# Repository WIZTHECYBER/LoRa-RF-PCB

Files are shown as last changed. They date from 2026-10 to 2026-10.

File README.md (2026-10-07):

# LoRa-RF-PCB







A custom PCB for long range radio frequency (LoRa) communication, built around an RP2040 and a Semtech SX1262 radio.


## Overview

I saw a guideline for a LoRa RF devboard in Forge Blueprint and decided to make my own. I did made schematics with help of AI and then designed and routed the PCB myself!!

###This PCB contains following components###
|MCU, radio, and flash all on one PCB, powered and programmed over USB-C.|

## Schematics Components 

| Part | Role |
|---|---|
| RP2040 | Microcontroller — runs everything |
| SX1262 | LoRa radio chip — handles the actual RF signal |
| 16MB flash | Stores the firmware |
| USB-C | Power and programming |
| RF switch + filter + antenna | Gets the signal in and out cleanly |
| Crystal oscillators | Reference clocks for the MCU and radio |
| LDO regulator | Power supply |
| Boot / Reset buttons | Standard flashing controls |

586520549-c6413717-07d1-4046-96aa-68a0806cc8d6

## Build Journey

This was my first time working with a 4-layer PCB, and it showed me why layer count matters — figuring it out took a while, but I learned a lot along the way. I used **Gemini** for help with the schematics.

From there, I moved on to placing components and routing the PCB myself. 


RF signal paths need to be straight and length-matched, which made that part of the routing genuinely tricky — it took about 2 days to fully route the board. Once the hardware was done, I wrote the firmware to bring it to life.


## Bill of Materials (BOM)

| Designator(s) | Part | Value / Footprint | Qty |
|---|---|---|---|
| U1 | RP2040 | Microcontroller, QFN-56 | 1 |
| U2 | SX1262IMLTRT | LoRa/FSK Transceiver, QFN-24 | 1 |
| U3 | W25Q128JVS | 16MB SPI Flash, SOIC-8 | 1 |
| U4 | PE4259 | RF Switch, SOT-363 | 1 |
| U5 | AP2112K-3.3 | 3.3V LDO Regulator, SOT-23-5 | 1 |
| USB_C | USB-C Receptacle | USB 2.0, 16-pin | 1 |
| J3 | Pin Socket, 1x04 | For a 0.96" OLED display | 1 |
| AE111 | U.FL Connector | For an external antenna | 1 |
| FL1 | Balun/Filter | Johanson 0900FM15K0039 | 1 |
| Y1 | Crystal | 32MHz (radio ref clock) | 1 |
| Y2 | Crystal | 12MHz (MCU ref clock) | 1 |
| BOOT | Tactile Switch | B3U-1000P | 1 |
| RESET | Tactile Switch | B3U-1000P | 1 |
| LED1 | LED | Blue | 1 |
| L1 | Inductor | 47nH | 1 |
| L2 | Inductor | 9.1nH | 1 |
| L3 | Inductor | 15µH (PA regulator) | 1 |
| R1 | Resistor | 100Ω | 1 |
| R2, R3, R7* | Resistor | 1kΩ | 3 |
| R4, R10 | Resistor | 10kΩ | 2 |
| R5, R6 | Resistor | 5.1kΩ (USB CC) | 2 |
| R8, R9 | Resistor | 27Ω (USB D+/D−) | 2 |
| R11, R12 | Resistor | 4.7kΩ | 2 |
| C1, C8, C9, C13, C14, C17–C23 | Capacitor | 100nF | 12 |
| C11, C12 | Capacitor | 27pF (crystal load) | 2 |
| C15, C16 | Capacitor | 1µF | 2 |
| C24, C25 | Capacitor | 10µF | 2 |
| C2 | Capacitor | 1nF | 1 |
| C3 | Capacitor | 39pF | 1 |
| C4, C5 | Capacitor | 3.3pF (RF matching) | 2 |
| C6 | Capacitor | 47pF | 1 |
| C7 | Capacitor | 47nF | 1 |
| C10 | Capacitor | 470nF (PA regulator) | 1 |

## Getting It Built

The RP2040, SX1262, and flash chip are all fine-pitch QFN parts, so this isn't a hand-soldering job — it needs PCBA (assembled by the fab) rather than a bare PCB.

## AI Use

Being upfront about it: I used Gemini for help with component selection and schematic routing, did the PCB design and routing myself!!.

## License

Released under [CERN-OHL-S](https://ohwr.org/cern_ohl_s_v2.txt) — feel free to fork it, fab it, and build on it.

Thanks for taking the time to look through this one — it was one of the more challenging boards I've built so far, and I learned a ton doing it. If you spot something worth improving, or you end up building one yourself, I'd genuinely love to hear about it. Feel free to open an issue or reach out.📡

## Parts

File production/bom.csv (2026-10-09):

Designator | Footprint | Quantity | Value | LCSC Part #
AE111 | U.FL_Hirose_U.FL-R-SMT-1_Vertical | 1 | Antenna | C88374
C1, C13, C14, C17, C18, C19, C20, C21, C22, C23, C8, C9 | 0603 | 12 | 100nF | C14663
C10 | 0603 | 1 | 470nF | C1623
C11, C12 | 0603 | 2 | 27pF | C1656
C15, C16 | 0603 | 2 | 1uF | C15849
C2 | 0603 | 1 | 1nF | C1588
C24, C25 | 0805 | 2 | 10uF | C15850
C3 | 0603 | 1 | 39pF | C302067
C4, C5 | 0603 | 2 | 3.3pF | C1660
C6 | 0603 | 1 | 47pF | C1671
C7 | 0603 | 1 | 47nF | C1622
FL1 | Balun_Johanson_0900FM15K0039 | 1 | 0900FM15K0039 | C5224443
J3 | PinSocket_1x04_P2.54mm_Vertical | 1 | Conn_01x04_Socket | C2897367
L1 | 0603 | 1 | 47nH | C98076
L2 | 0603 | 1 | 9.1nH | C251803
L3 | 0805 | 1 | 15uH | C383402
LED1 | 0603 | 1 | BLUE | C2288
R1 | 0603 | 1 | 100 | C22775
R10, R4 | 0603 | 2 | 10K | C25804
R11, R12 | 0603 | 2 | 4.7K | C23162
R2, R3, R7 | 0603 | 3 | 1K | C21190
R5, R6 | 0603 | 2 | 5.1K | C23186
R8, R9 | 0603 | 2 | 27 ohm | C25190
SW1 | SW_SPST_B3U-1000P | 1 | BOOT | C231329
SW2 | SW_SPST_B3U-1000P | 1 | RESET | C231329
U1 | QFN-56-1EP_7x7mm_P0.4mm_EP3.2x3.2mm | 1 | RP2040 | C2040
U2 | QFN-24-1EP_4x4mm_P0.5mm_EP2.6x2.6mm | 1 | SX1262IMLTRT | C191341
U3 | SOIC-8_5.3x5.3mm_P1.27mm | 1 | W25Q128JVS | C97521
U4 | SOT-363_SC-70-6 | 1 | PE4259 | C470892
U5 | SOT-23-5 | 1 | AP2112K-3.3 | C51118
USB-C | USB_C_Receptacle_HRO_TYPE-C-31-M-12 | 1 | USB_C_Receptacle_USB2.0_16P | C165948
Y1 | Crystal_SMD_3225-4Pin_3.2x2.5mm_HandSoldering | 1 | 32MHz | C9009
Y2 | Crystal_SMD_3225-4Pin_3.2x2.5mm_HandSoldering | 1 | 12MHz | C9002

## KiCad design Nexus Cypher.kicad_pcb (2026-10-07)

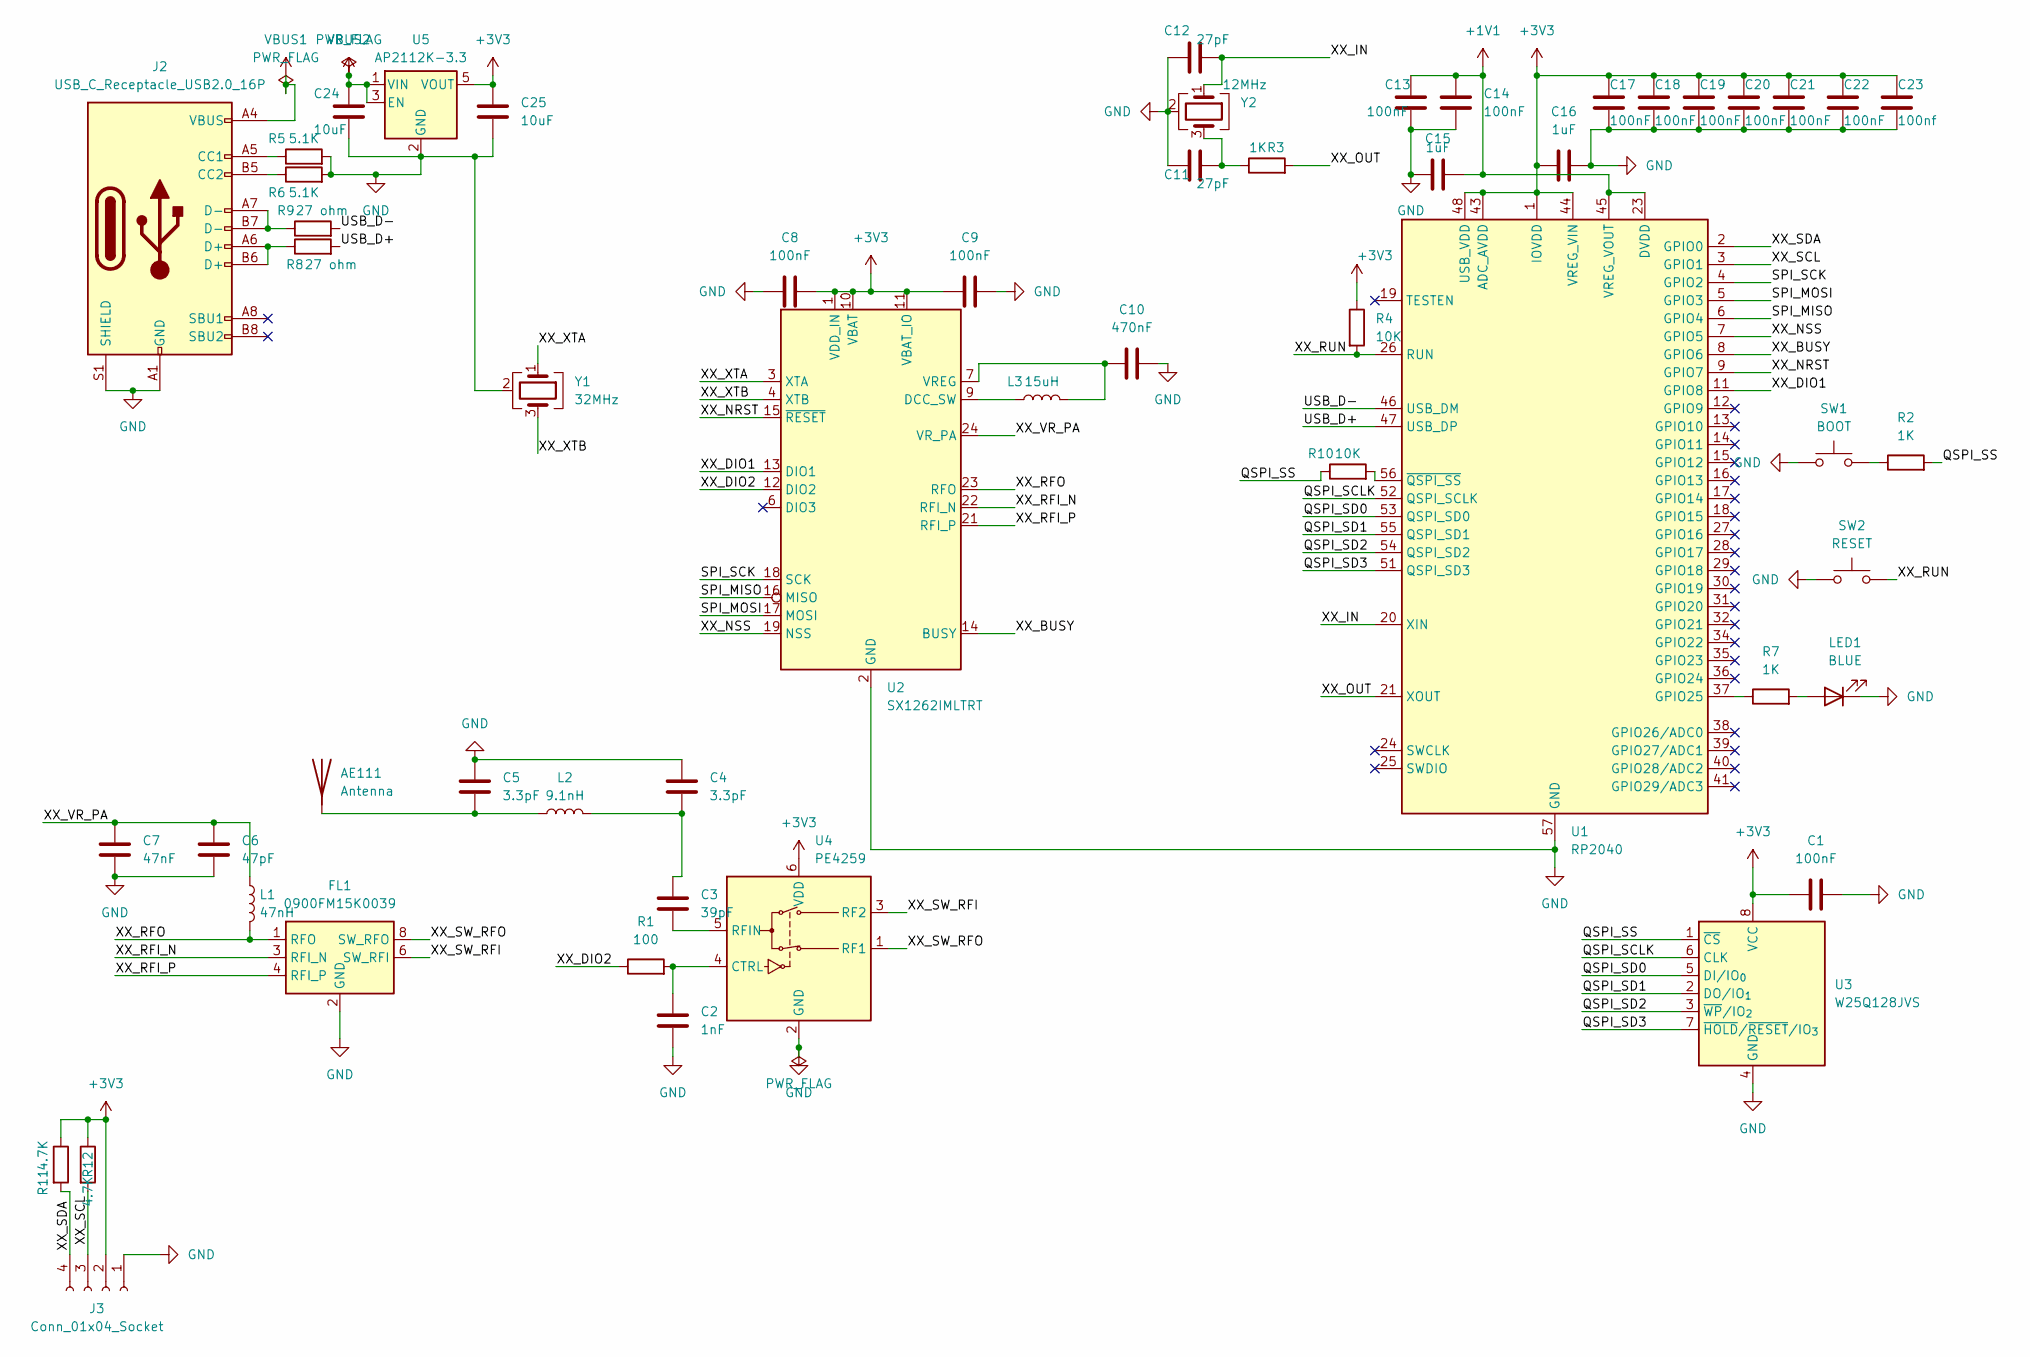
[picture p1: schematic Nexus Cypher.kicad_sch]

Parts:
AE111: Antenna; U.FL_Hirose_U.FL-R-SMT-1_Vertical
C1, C8, C9, C13, C14, C17, C18, C19, C20, C21, C22: 100nF; C_0603_1608Metric
C2: 1nF; C_0603_1608Metric
C3: 39pF; C_0603_1608Metric
C4, C5: 3.3pF; C_0603_1608Metric
C6: 47pF; C_0603_1608Metric
C7: 47nF; C_0603_1608Metric
C10: 470nF; C_0603_1608Metric
C11, C12: 27pF; C_0603_1608Metric
C15, C16: 1uF; C_0603_1608Metric
C23: 100nf; C_0603_1608Metric
C24, C25: 10uF; C_0805_2012Metric
FL1: 0900FM15K0039; Balun_Johanson_0900FM15K0039
J2: USB_C_Receptacle_USB2.0_16P; USB_C_Receptacle_HRO_TYPE-C-31-M-12
J3: Conn_01x04_Socket; PinSocket_1x04_P2.54mm_Vertical
L1: 47nH; L_0603_1608Metric
L2: 9.1nH; L_0603_1608Metric
L3: 15uH; L_0805_2012Metric
LED1: BLUE; LED_0603_1608Metric
R1: 100; R_0603_1608Metric
R2, R3, R7: 1K; R_0603_1608Metric
R4, R10: 10K; R_0603_1608Metric
R5, R6: 5.1K; R_0603_1608Metric
R8, R9: 27 ohm; R_0603_1608Metric
R11, R12: 4.7K; R_0603_1608Metric
SW1: BOOT; SW_SPST_B3U-1000P
SW2: RESET; SW_SPST_B3U-1000P
U1: RP2040; QFN-56-1EP_7x7mm_P0.4mm_EP3.2x3.2mm
U2: SX1262IMLTRT; QFN-24-1EP_4x4mm_P0.5mm_EP2.6x2.6mm
U3: W25Q128JVS; SOIC-8_5.3x5.3mm_P1.27mm
U4: PE4259; SOT-363_SC-70-6
U5: AP2112K-3.3; SOT-23-5
Y1: 32MHz; Crystal_SMD_3225-4Pin_3.2x2.5mm_HandSoldering
Y2: 12MHz; Crystal_SMD_3225-4Pin_3.2x2.5mm_HandSoldering

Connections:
+1V1: C13.1, C14.1, C15.2, U1.23 (DVDD), U1.45 (VREG_VOUT), U1.50 (DVDD)
+3V3: C1.1, C8.2, C9.1, C16.1, C17.1, C18.1, C19.1, C20.1, C21.1, C22.1, C23.1, C25.1, J3.2, R4.1, R11.1, R12.1, U1.1 (IOVDD), U1.10 (IOVDD), U1.22 (IOVDD), U1.33 (IOVDD), U1.42 (IOVDD), U1.43 (ADC_AVDD), U1.44 (VREG_VIN), U1.48 (USB_VDD), U1.49 (IOVDD), U2.1 (VDD_IN), U2.10 (VBAT), U2.11 (VBAT_IO), U3.8 (VCC), U4.6 (VDD), U5.5 (VOUT)
/QSPI_SCLK: U1.52 (QSPI_SCLK), U3.6 (CLK)
/QSPI_SD0: U1.53 (QSPI_SD0), U3.5 (DI/IO_{0})
/QSPI_SD1: U1.55 (QSPI_SD1), U3.2 (DO/IO_{1})
/QSPI_SD2: U1.54 (QSPI_SD2), U3.3 (~WP/IO_{2})
/QSPI_SD3: U1.51 (QSPI_SD3), U3.7 (~HOLD/~RESET/IO_{3})
/QSPI_SS: R2.2, R10.1, U3.1 (~CS)
/SPI_MISO: U1.6 (GPIO4), U2.16 (MISO)
/SPI_MOSI: U1.5 (GPIO3), U2.17 (MOSI)
/SPI_SCK: U1.4 (GPIO2), U2.18 (SCK)
/USB_D+: R8.2, U1.47 (USB_DP)
/USB_D-: R9.2, U1.46 (USB_DM)
/XX_BUSY: U1.8 (GPIO6), U2.14 (BUSY)
/XX_DIO1: U1.11 (GPIO8), U2.13 (DIO1)
/XX_DIO2: R1.1, U2.12 (DIO2)
/XX_IN: C12.2, U1.20 (XIN), Y2.1
/XX_NRST: U1.9 (GPIO7), U2.15 (~RESET)
/XX_NSS: U1.7 (GPIO5), U2.19 (NSS)
/XX_OUT: R3.2, U1.21 (XOUT)
/XX_RFI_N: FL1.3 (RFI_N), U2.22 (RFI_N)
/XX_RFI_P: FL1.4 (RFI_P), U2.21 (RFI_P)
/XX_RFO: FL1.1 (RFO), L1.2, U2.23 (RFO)
/XX_RUN: R4.2, SW2.2, U1.26 (RUN)
/XX_SCL: J3.3, R12.2, U1.3 (GPIO1)
/XX_SDA: J3.4, R11.2, U1.2 (GPIO0)
/XX_SW_RFI: FL1.6 (SW_RFI), U4.3 (RF2)
/XX_SW_RFO: FL1.8 (SW_RFO), U4.1 (RF1)
/XX_VR_PA: C6.1, C7.1, L1.1, U2.24 (VR_PA)
/XX_XTA: U2.3 (XTA), Y1.1
/XX_XTB: U2.4 (XTB), Y1.3
GND: C1.2, C2.2, C4.2, C5.2, C6.2, C7.2, C8.1, C9.2, C10.2, C11.2, C12.1, C13.2, C14.2, C15.1, C16.2, C17.2, C18.2, C19.2, C20.2, C21.2, C22.2, C23.2, C24.2, C25.2, FL1.2 (GND), FL1.5 (GND), FL1.7 (GND), FL1.9 (GND), FL1.10 (GND), J2.A1 (GND), J2.A12 (GND), J2.B1 (GND), J2.B12 (GND), J2.S1 (SHIELD), J3.1, LED1.1 (K), R5.2, R6.2, SW1.1, SW2.1, U1.57 (GND), U2.2 (GND), U2.5 (GND), U2.8 (GND), U2.20 (GND), U2.25 (GND), U3.4 (GND), U4.2 (GND), U5.2 (GND), Y1.2 (G), Y1.4 (G), Y2.2 (G), Y2.4 (G); also elsewhere on the board
unnamed: AE111.1 (A_1), C5.1, L2.1
unnamed: C3.1, C4.1, L2.2
unnamed: C11.1, R3.1, Y2.3
unnamed 35: J2.A5 (CC1), R5.1; also elsewhere on the board
unnamed 36: J2.B5 (CC2), R6.1; also elsewhere on the board
unnamed 37: J2.A6 (D+), J2.B6 (D+), R8.1; also elsewhere on the board
unnamed 38: J2.A7 (D-), J2.B7 (D-), R9.1; also elsewhere on the board
unnamed: J2.A4 (VBUS), J2.A9 (VBUS), J2.B4 (VBUS), J2.B9 (VBUS)
unnamed: LED1.2 (A), R7.2
unnamed: R2.1, SW1.2
unnamed: R7.1, U1.37 (GPIO25)
unnamed: R10.2, U1.56 (~QSPI_SS)
unnamed: L3.1, U2.9 (DCC_SW)
unnamed: C10.1, L3.2, U2.7 (VREG)
unnamed: C2.1, R1.2, U4.4 (CTRL)
unnamed: C3.2, U4.5 (RFIN)
VBUS2: C24.1, U5.1 (VIN), U5.3 (EN)

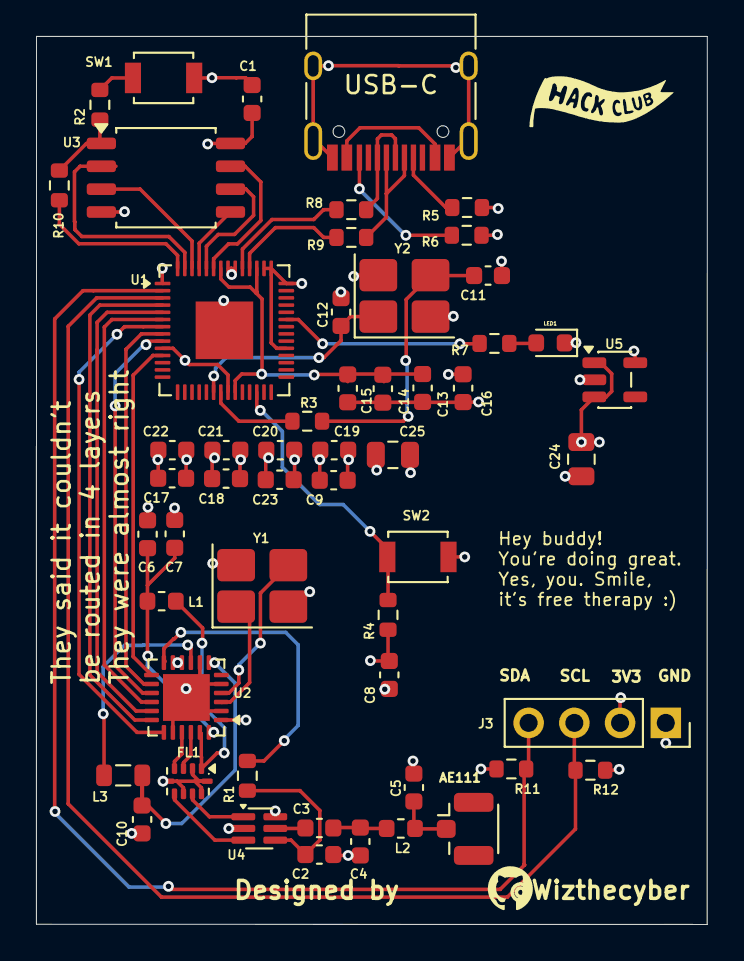
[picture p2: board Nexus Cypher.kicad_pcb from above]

Board: 4 copper layers, 37.3 x 49.3 mm, 54 parts (0 on the bottom side), 49 nets.

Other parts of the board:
USB-C: USB_C_Receptacle_USB2.0_16P; USB_C_Receptacle_HRO_TYPE-C-31-M-12

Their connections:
GND: USB-C.A1 (GND), USB-C.A12 (GND), USB-C.B1 (GND), USB-C.B12 (GND), USB-C.S1 (SHIELD); also elsewhere on the board
unnamed 35: USB-C.A5 (CC1); also elsewhere on the board
unnamed 36: USB-C.B5 (CC2); also elsewhere on the board
unnamed 37: USB-C.A6 (D+), USB-C.B6 (D+); also elsewhere on the board
unnamed 38: USB-C.A7 (D-), USB-C.B7 (D-); also elsewhere on the board
VBUS1: USB-C.A4 (VBUS), USB-C.A9 (VBUS), USB-C.B4 (VBUS), USB-C.B9 (VBUS)

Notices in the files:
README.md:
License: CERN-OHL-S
